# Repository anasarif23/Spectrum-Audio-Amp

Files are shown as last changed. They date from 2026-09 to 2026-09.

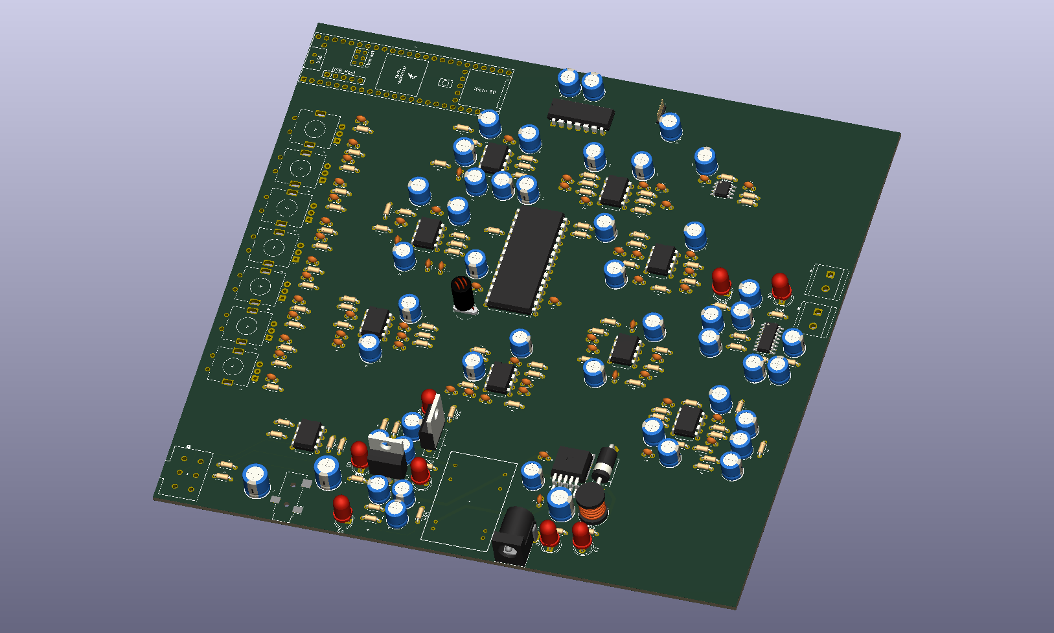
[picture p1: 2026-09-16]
Audio_Amplifier 3D-PIC.png

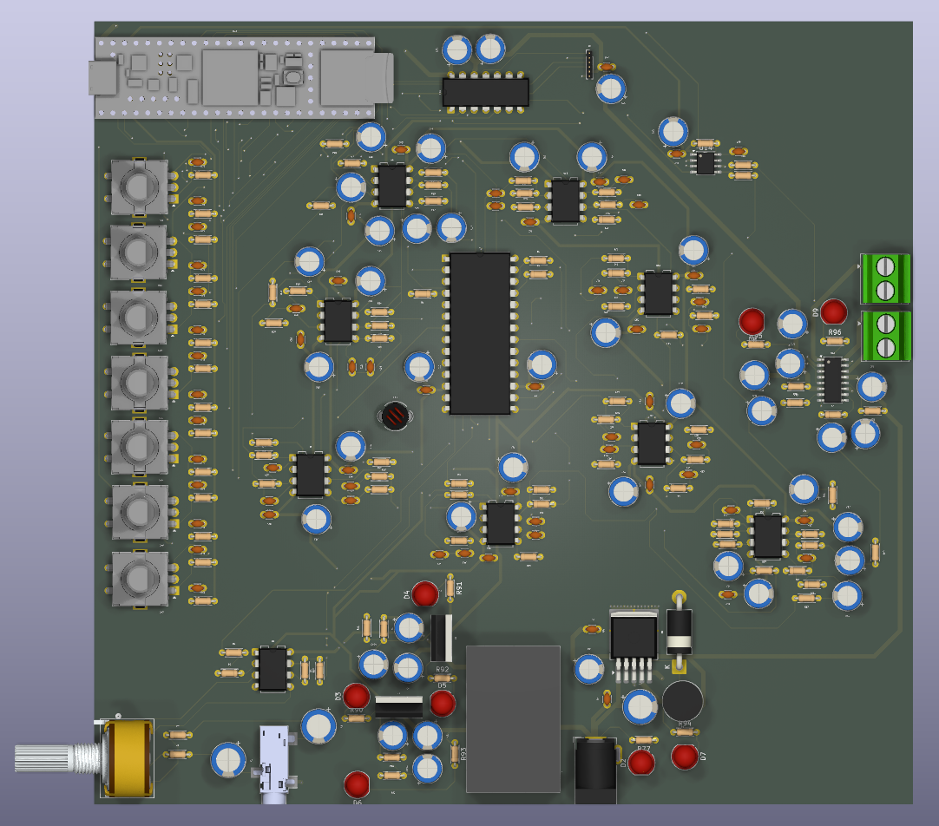
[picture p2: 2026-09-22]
PICS & PDFS/Audio_Amplifier PERFECY SQUARE.png

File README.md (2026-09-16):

## Version 0

The first version of the schematic, completed while learning KiCad fundamentals. This version has some design mistakes that I identified during review, including [add specifics if you can — e.g. incorrect regulator pinout, missing decoupling capacitors, etc.]. I used Claude as a learning resource throughout this stage to understand regulator behavior, KiCad's schematic tools, and best practices for power supply design.

📄 See `Advanced Audio Amplifier Schematic.pdf` for the full Version 0 schematic.

## Version 1

A revised, cleaner version of the schematic with the Version 0 mistakes corrected and the overall layout better organized. This version is still in progress — the schematic is further along, and I'm now working on completing the full PCB layout.

🖼️ See `Audio Amplifier Version 1.png` for the current schematic.

## Version 2

The PCB layout stage — all components have been placed on the board. Routing has not started yet; that's the next step.

📄 See `Audio_Amplifier.pdf` for the schematic and `Audio_Amplifier PCB FULL LAYOUT.pdf` for the current component placement.

🖼️ See `Audio_Amplifier 3D-PIC.png` for a 3D render of the board as placed so far.

---

## Bill of Materials (from schematic)

### Active Components

| Ref | Part | Description |
|-----|---|---|
| U1, U6–U13 | NE5532 | Dual op-amp — used across the pre-amp stage and the 7 gyrator filter bands |
| U2 | LM317-TO220 | Adjustable positive linear regulator |
| U3 | LM337-TO220 | Adjustable negative linear regulator |
| U4 | LM2596S-5 | Switching buck regulator (5V rail) |
| U5 | LMC835N | Graphic equalizer IC |
| U14 | MSGEQ7 | 7-band spectrum analyzer IC |
| U15 | Teensy 4.1 | Microcontroller |
| U16 | SN74AHCT125N | Quad buffer / 3.3V logic level shifter |
| U18 | PAM8403D | Class-D speaker amplifier |
| PS1 | DCWN03A-12 | Isolated DC-DC converter |
| D1 | 1N5822 | Schottky diode |
| D2–D9 | LED | Status/indicator LEDs |
| SW1–SW7 | Rotary Encoder | 7-band control knobs |
| RV1 | 10k | Potentiometer |
| L1 | 33µH | Inductor (buck regulator) |
| FB1 | Ferrite Bead | EMI suppression |
| J1 | SJ-3523-SMT | Audio input jack |
| J2 | Barrel Jack | 12V power input |
| J3, J4 | Screw_Terminal_01x02 | Power/output connections |
| J6 | Conn_01x06 | Pin header |

### Passives

Roughly 96 resistors (R1–R96) and 110 capacitors (C1–C110) make up the gyrator filter networks (tuned for the 63Hz–16kHz bands), op-amp gain/bias networks, and decoupling/filtering throughout the board. Full reference-designator values are in the schematic (`Audio_Amplifier.pdf`).

---

## Status

🚧 **In progress** — schematic complete (Version 1); PCB component placement complete (Version 2), routing still to be done.

## Tools Used

- KiCad (schematic capture, PCB layout)
- NE5532 dual op-amps (pre-amp and gyrator filter stages)
- LM317 / LM337 adjustable linear regulators, LM2596S-5 switching regulator
- MSGEQ7 spectrum analyzer IC, LMC835N graphic equalizer IC
- Teensy 4.1 microcontroller
- PAM8403D class-D amplifier

## What I Learned

Iterating between Version 0 and Version 1 taught me to catch design errors early through review rather than discovering them at the prototyping stage — a habit I now apply to every new project. I also used Claude as a learning tool throughout this project to fill gaps in my coursework, particularly around regulator dropout behavior and KiCad workflow, then applied that understanding directly to my design decisions.

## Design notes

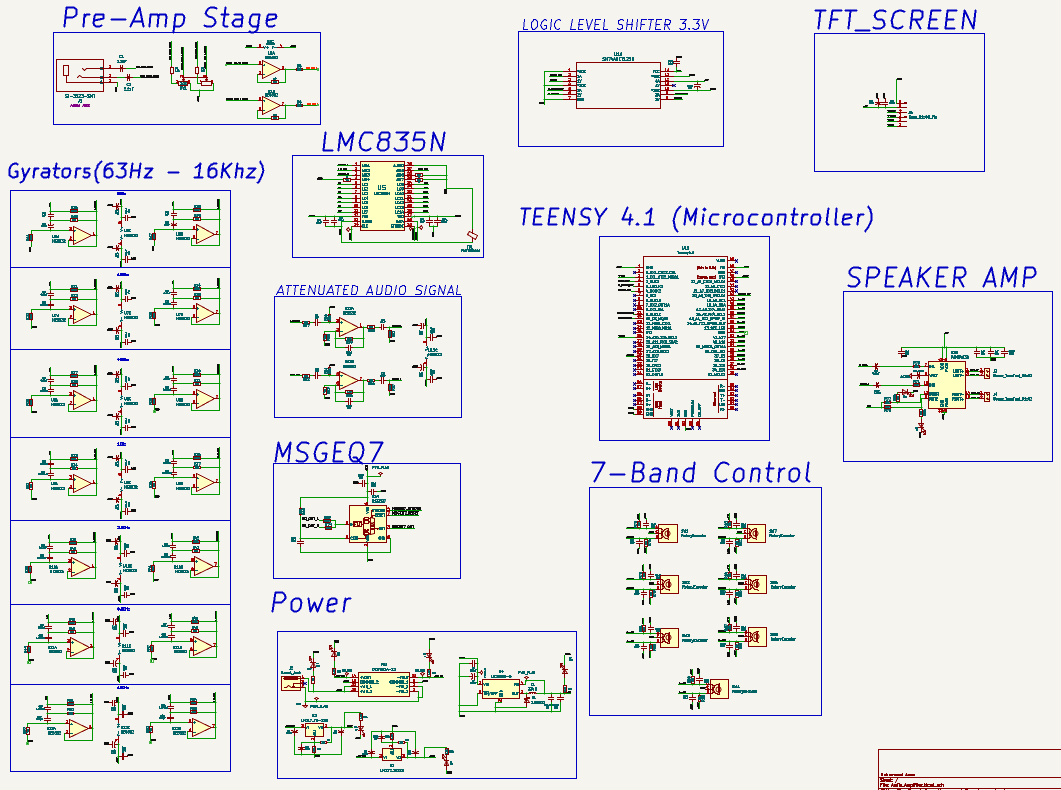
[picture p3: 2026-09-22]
Scehmatic PNG.png

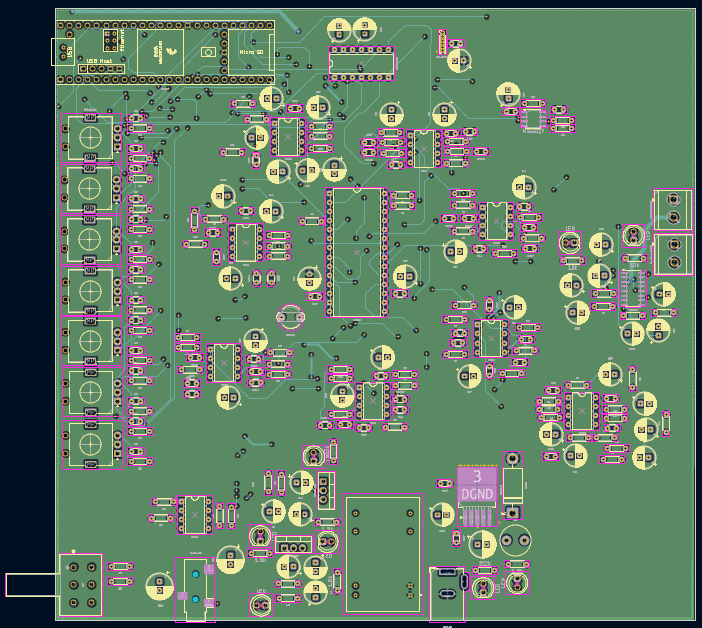
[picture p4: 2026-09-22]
PICS & PDFS/DGND.png

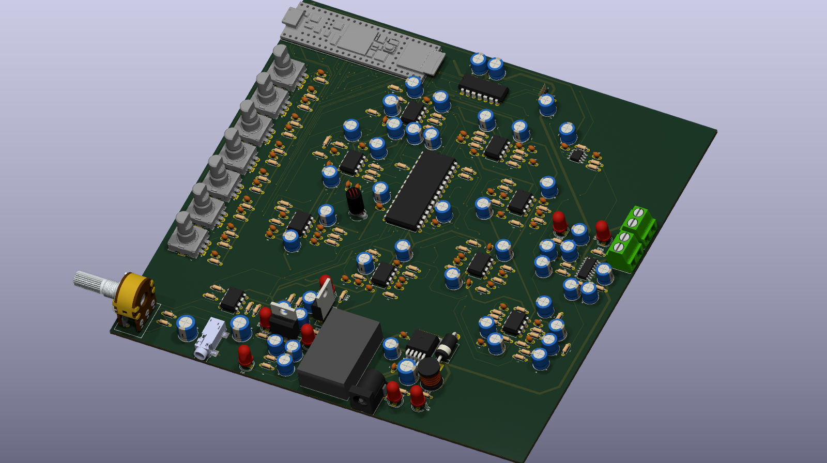
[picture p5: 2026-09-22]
PICS & PDFS/Audio_Amplifier.png

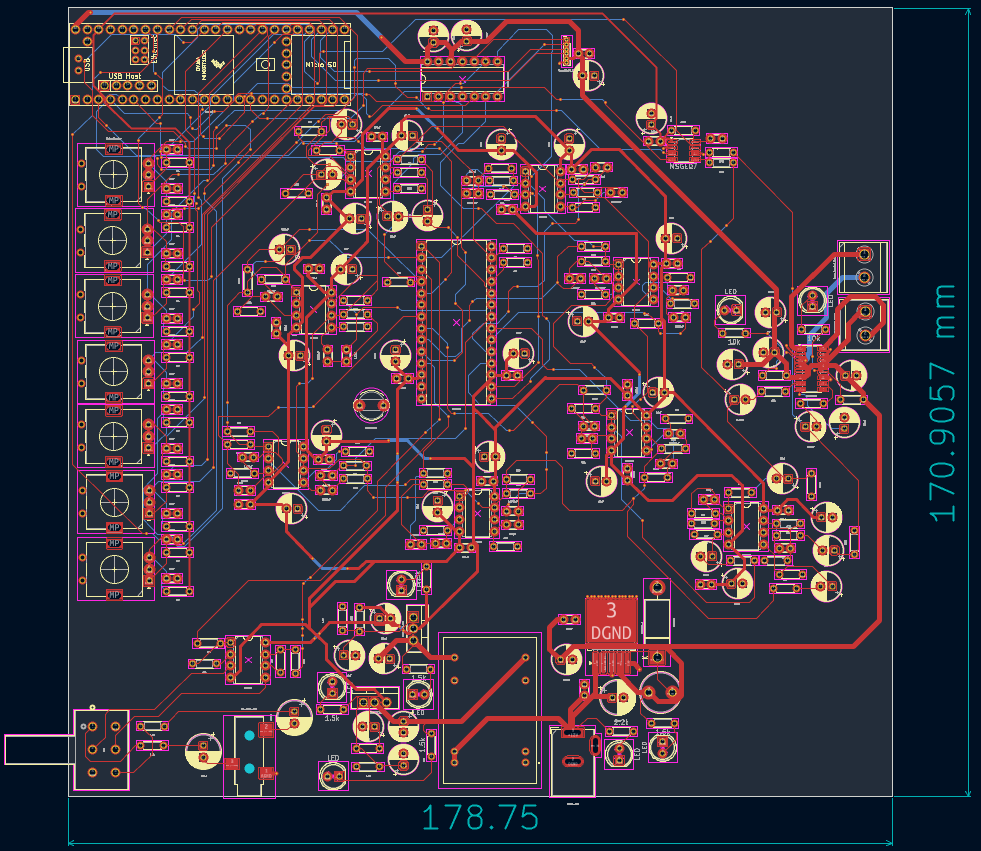
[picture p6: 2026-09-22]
PICS & PDFS/Screenshot 2026-09-20 064418.png

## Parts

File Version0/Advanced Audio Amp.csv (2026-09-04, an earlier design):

Reference | Qty | Value | DNP | Exclude from BOM | Exclude from Board | Footprint | Datasheet
A1 | 1 | Arduino_Nano_v3.x |  |  |  | Module:Arduino_Nano | http://www.mouser.com/pdfdocs/Gravitech_Arduino_Nano3_0.pdf
C1,C2,C4,C8 | 4 | 1uF
C3,C5,C9,C11,C41,C42,C61,C63,C65,C67,C76,C79 | 12 | 10uF
C6,C58,C59 | 3 | 33pF
C7,C10,C14,C43,C44,C45,C46,C47,C48,C49,C50,C51,C52,C53,C54,C55,C56,C57,C60,C62,C64,C66,C68,C74,C75,C80 | 26 | 100nF
C12,C13 | 2 | 2.2uF
C15,C16 | 2 | 0.1uF
C17,C19 | 2 | 0.033uF
C18,C20 | 2 | 0.47uF
C21,C23 | 2 | 0.015uF
C22,C24 | 2 | 0.15uF
C25,C27 | 2 | 0.0068uF
C26,C28 | 2 | 0.068uF
C29,C31 | 2 | 0.0033uF
C30,C32 | 2 | 0.022uF
C33,C35 | 2 | 0.0015uF
C34,C36 | 2 | 0.01uF
C37,C39 | 2 | 680pF
C38,C40 | 2 | 0.0047uF
C69 | 1 | 100pF
C70,C71 | 2 | C_Small_US
C72 | 1 | C_Small
J1 | 1 | AudioPlug3
LS3,LS4 | 2 | 4Ω 3W
R1,R2,R17,RV1,RV3,RV4,RV5,RV6,RV7,RV8 | 10 | 10k
R3,R12,R19,R22,R23,R25,R26,R28,R29,R31,R32,R34,R35,R38,R41,R44,R47,R50,R53,R56,R63,R64,R65,R66 | 24 | 100k
R4,R5 | 2 | 22k
R6,R10,R18,R59 | 4 | 100
R7,R14 | 2 | 470
R8,R9,R11,R13 | 4 | 6.8k
R15 | 1 | 200k
R16,RV2 | 2 | 10K
R20,R21,R24,R27,R30,R33,R36,R39,R42,R45,R48,R51,R54,R57 | 14 | 680
R37,R40,R43,R46 | 4 | 82K
R49,R52 | 2 | 62k
R55,R58 | 2 | 47k
R60,R61,R62 | 3 | 47K
R67,R68,R69,R70,R71,R72,R73 | 7 | 47
R74,R75,R76,R78 | 4 | 1k
R77 | 1 | R_Small_US
U1,U2,U3,U4,U5,U6,U8,U11,U12 | 9 | NE5532 |  |  |  |  | http://www.ti.com/lit/ds/symlink/ne5532.pdf
U7,U14 | 2
U9 | 1 | PAM8403D |  |  |  | Package_SO:SOIC-16_3.9x9.9mm_P1.27mm | https://www.diodes.com/assets/Datasheets/products_inactive_data/PAM8403.pdf
U10 | 1 | MSGEQ7 |  |  |  |  | http://mix-sig.com/images/datasheets/MSGEQ7.pdf
U13 | 1 | CD4051B |  |  |  |  | http://www.ti.com/lit/ds/symlink/cd4052b.pdf

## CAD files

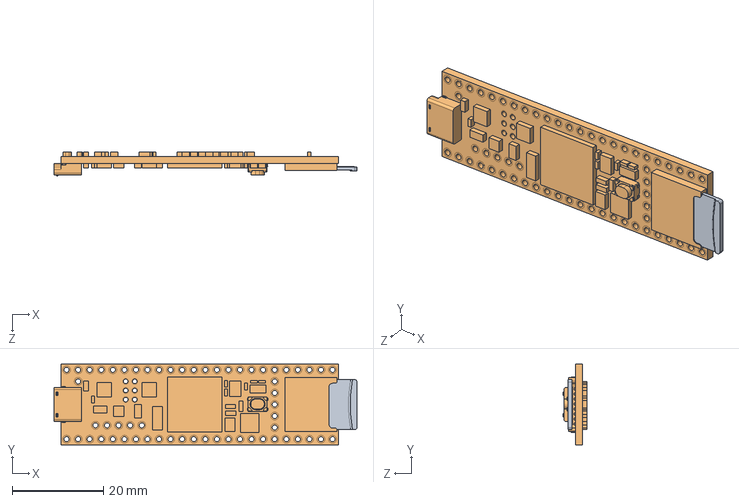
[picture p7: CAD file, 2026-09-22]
CIRCUIT BOARD,TEENSY 4.10.STEP
66.6 x 17.8 x 5.27 mm

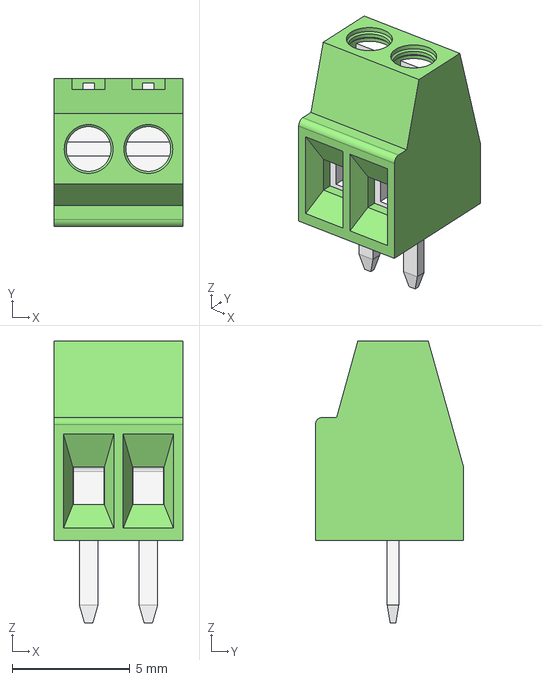
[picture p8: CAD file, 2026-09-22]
KF128-2.54-2P.step
5.48 x 6.30 x 12.0 mm
Connector_body

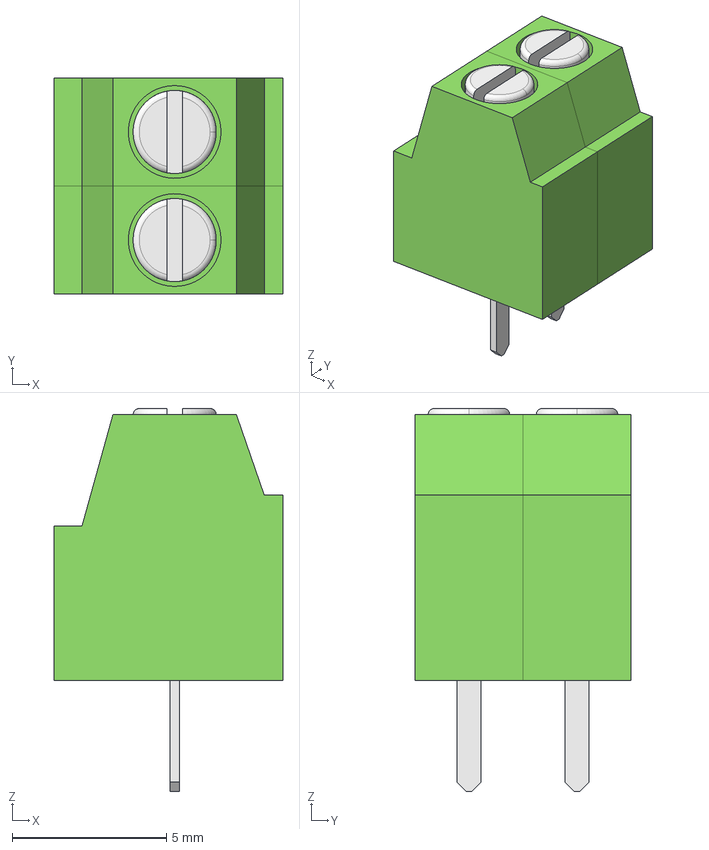
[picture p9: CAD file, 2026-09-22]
KF128-3.5-2P.step
7.40 x 7.00 x 12.4 mm

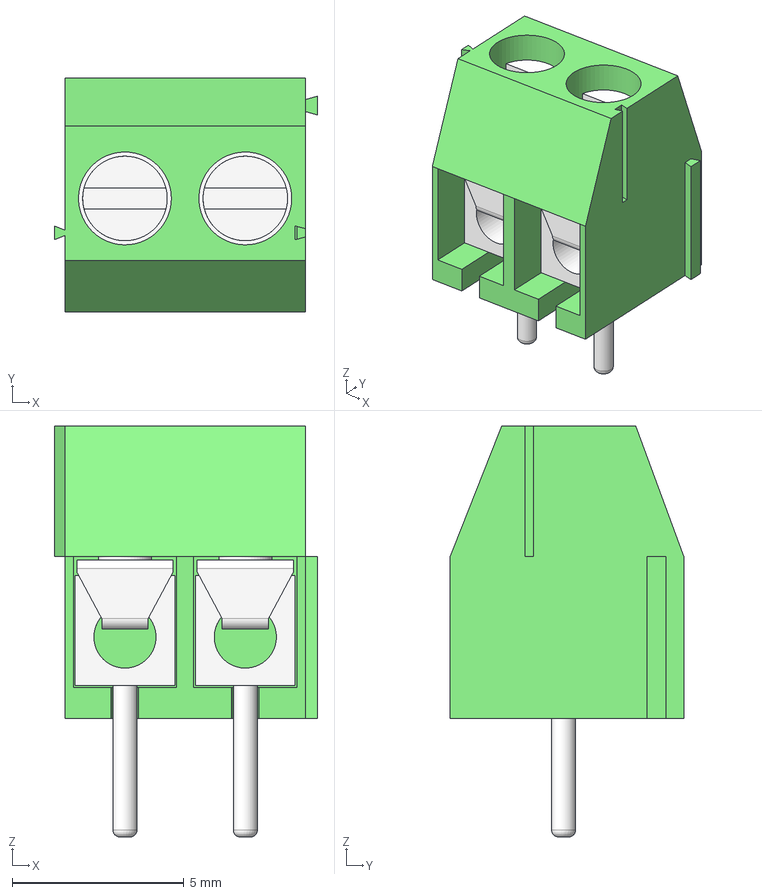
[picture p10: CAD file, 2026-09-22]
KF350-2p.step
7.65 x 6.80 x 11.9 mm
Corps
Conn_1
Conn_2
blade_1
blade_2
Vis_1
Vis_001

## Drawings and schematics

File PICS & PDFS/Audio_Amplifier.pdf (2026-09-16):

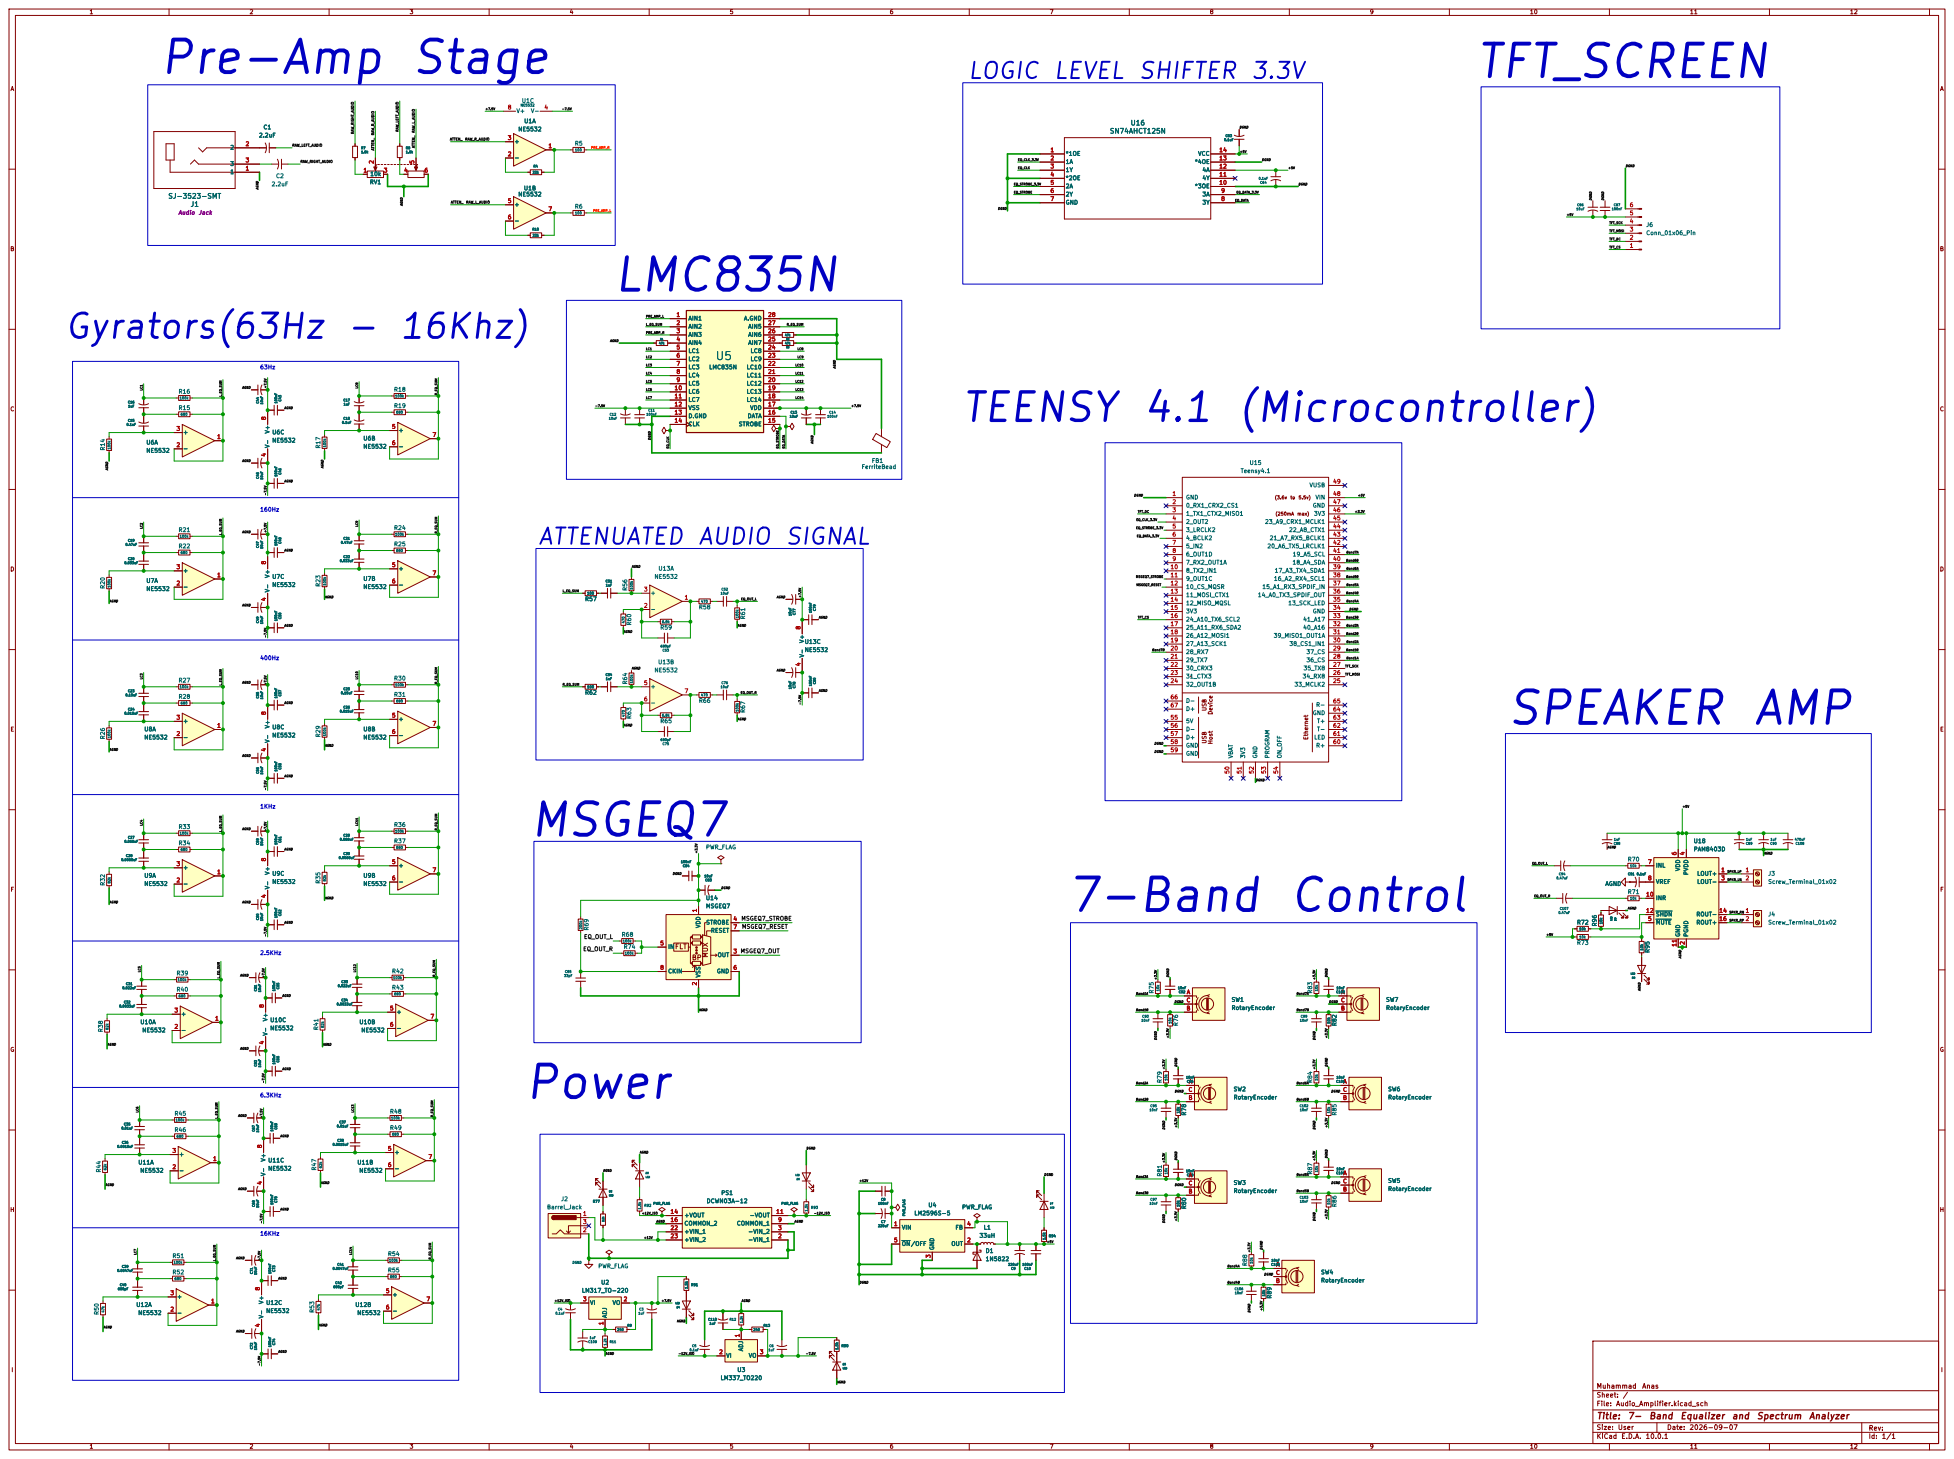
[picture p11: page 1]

100nF USB USB Device Host

Muhammad Anas
Sheet: /
File: Audio_Amplifier.kicad_sch
Title: 7- Band Equalizer and Spectrum Analyzer

Size: User | Rev:
KiCad E.D.A. 10.0.1 | Id: 1/1

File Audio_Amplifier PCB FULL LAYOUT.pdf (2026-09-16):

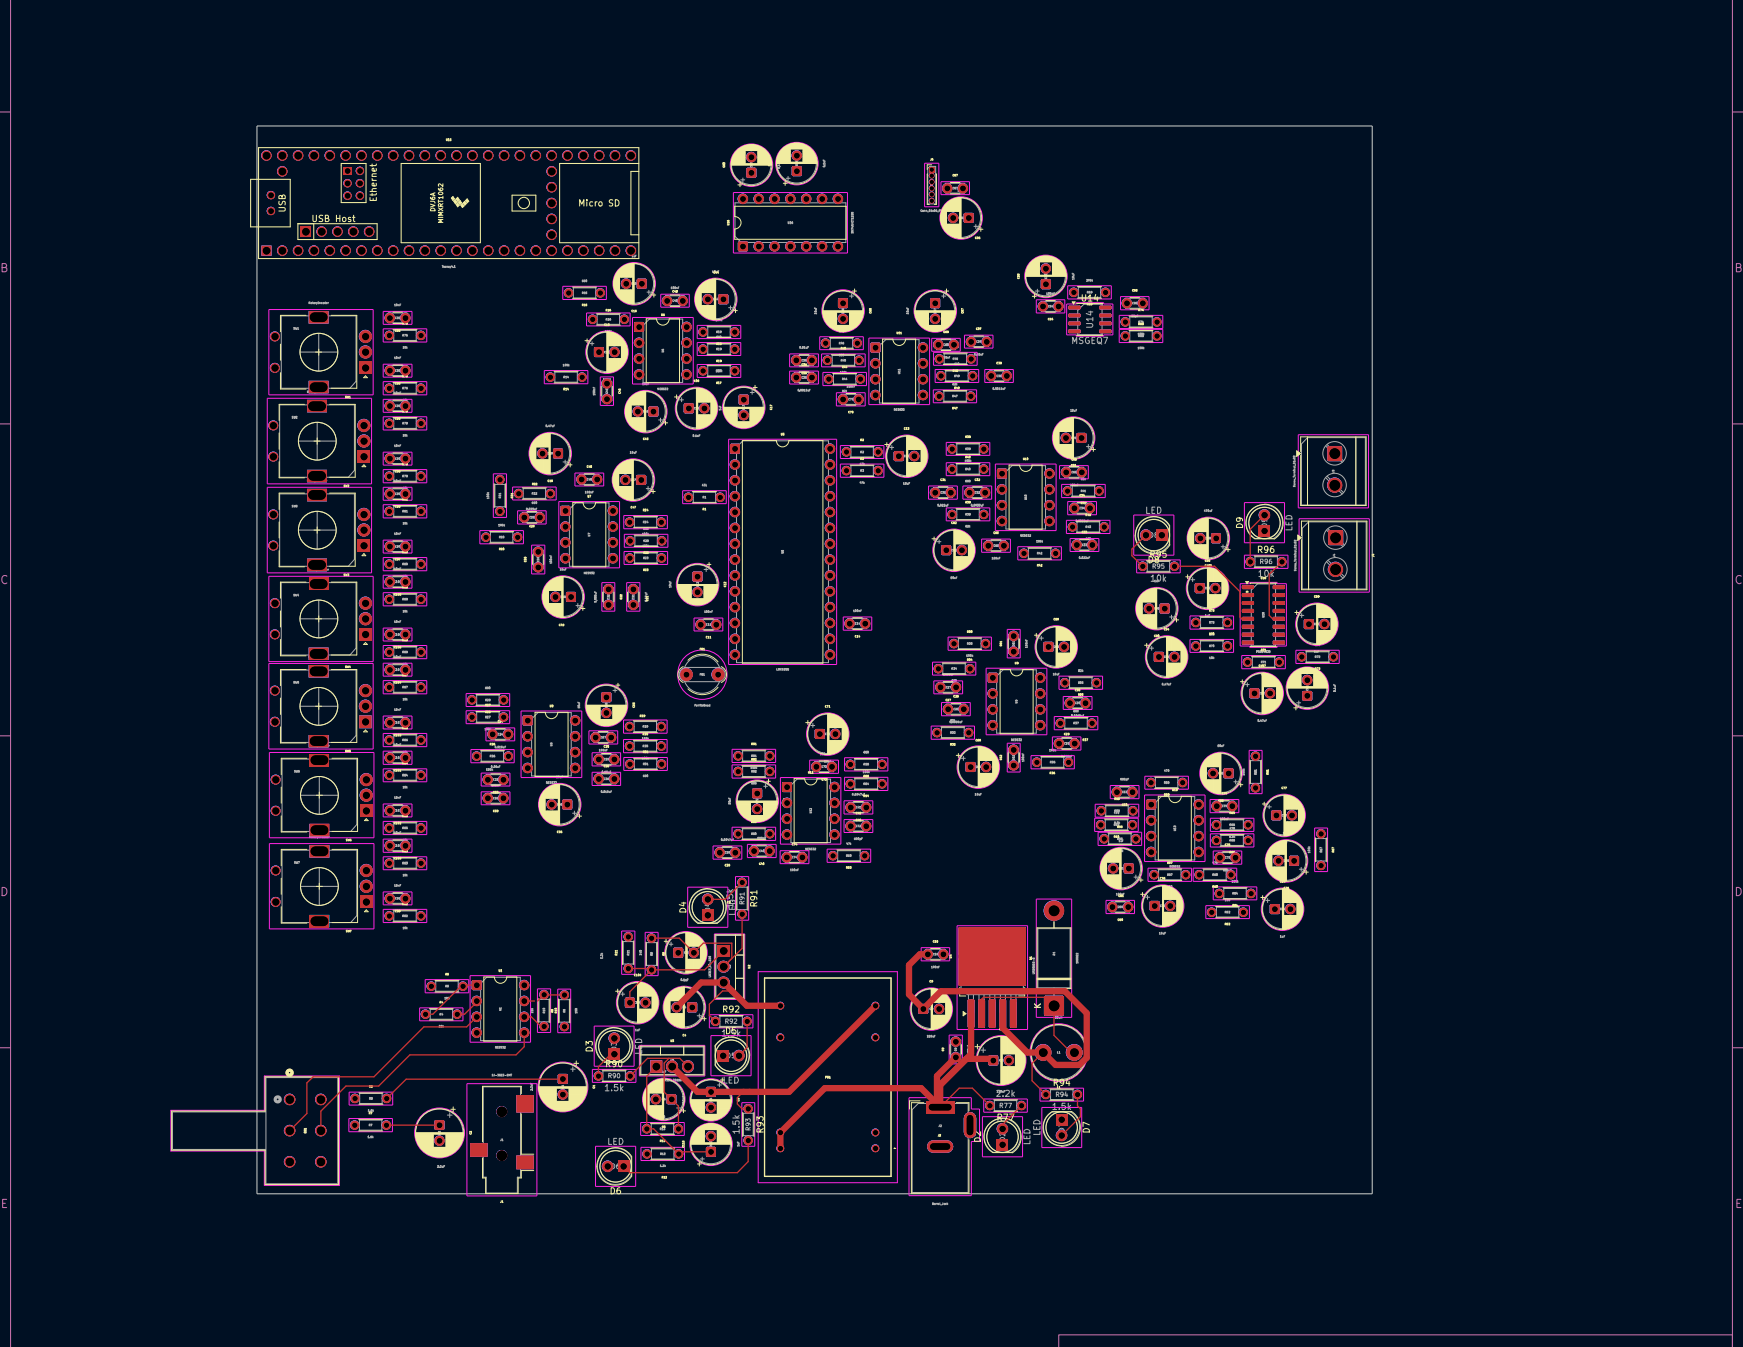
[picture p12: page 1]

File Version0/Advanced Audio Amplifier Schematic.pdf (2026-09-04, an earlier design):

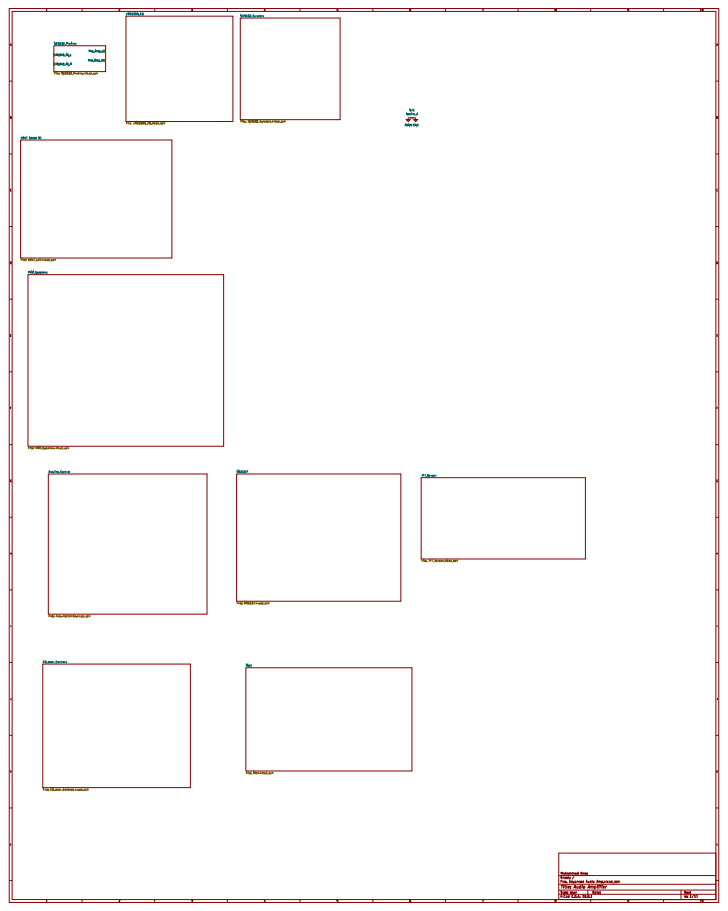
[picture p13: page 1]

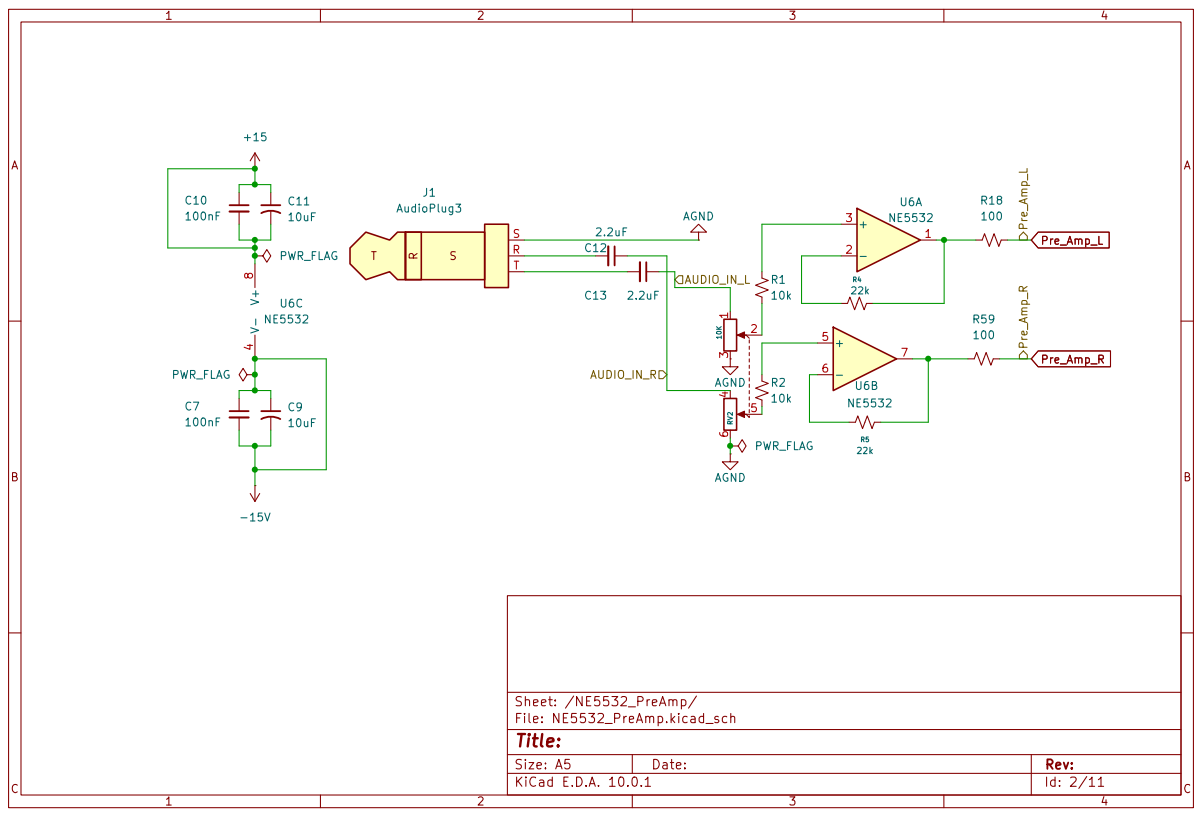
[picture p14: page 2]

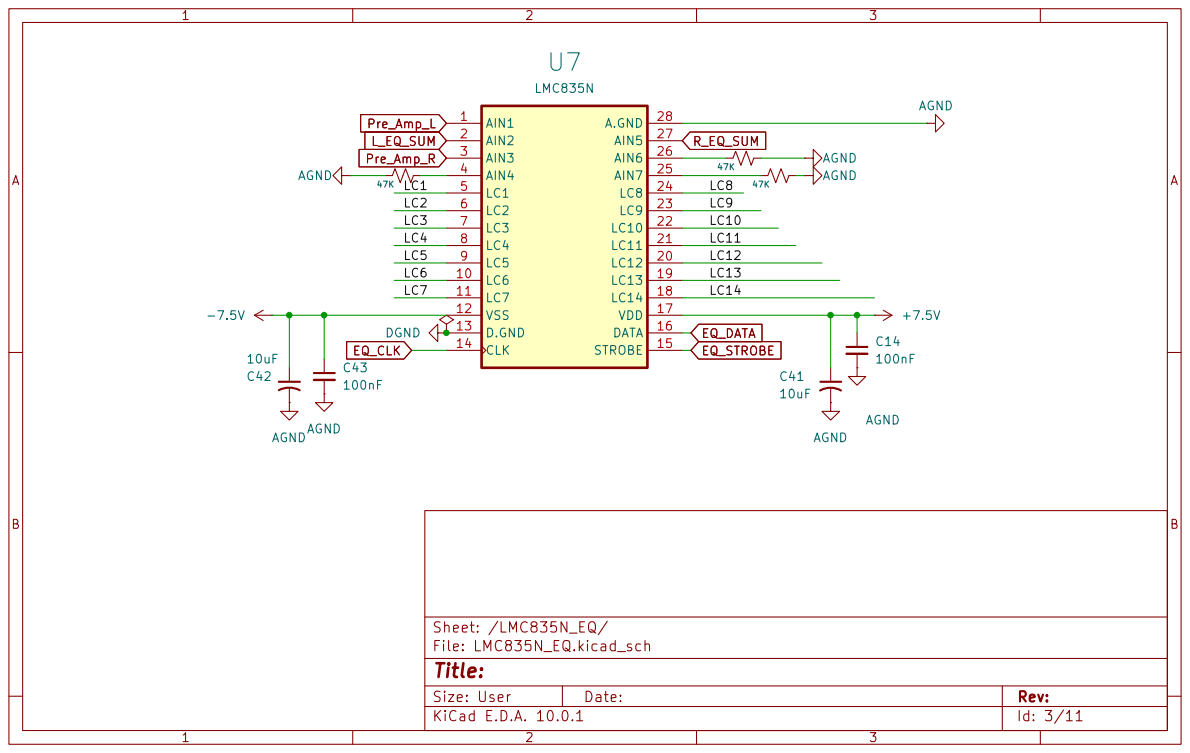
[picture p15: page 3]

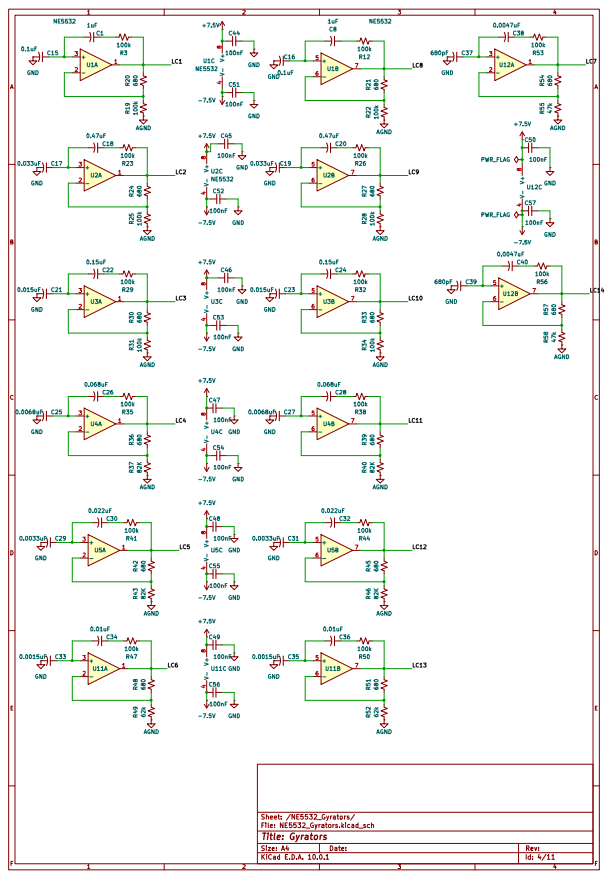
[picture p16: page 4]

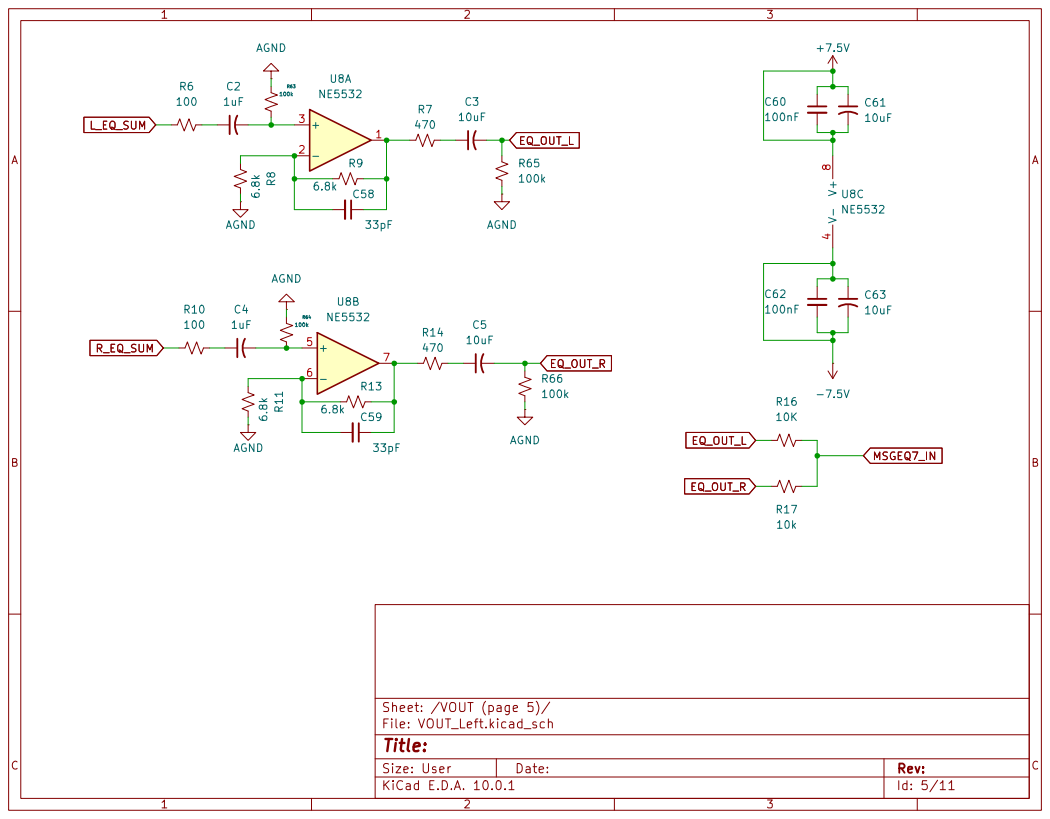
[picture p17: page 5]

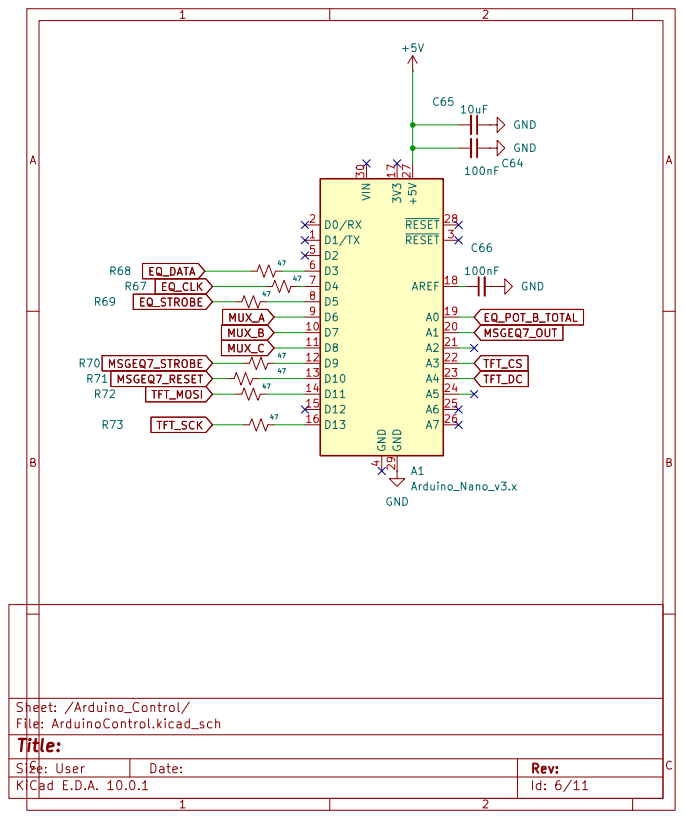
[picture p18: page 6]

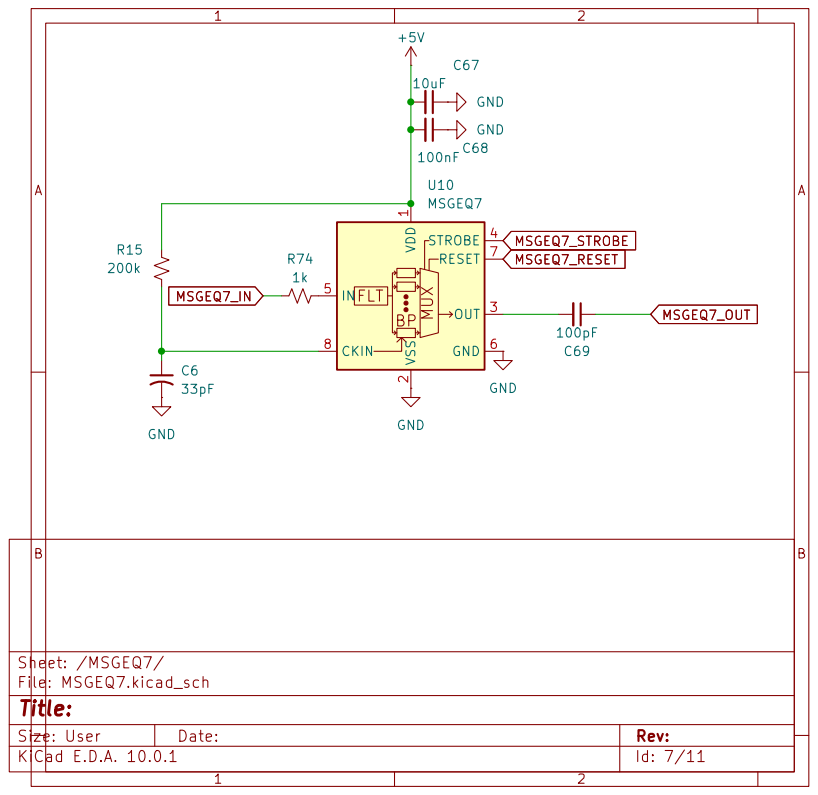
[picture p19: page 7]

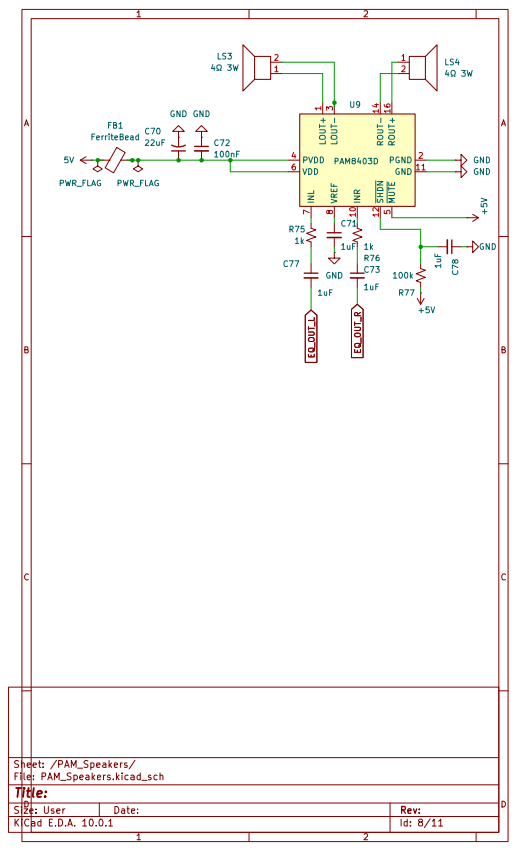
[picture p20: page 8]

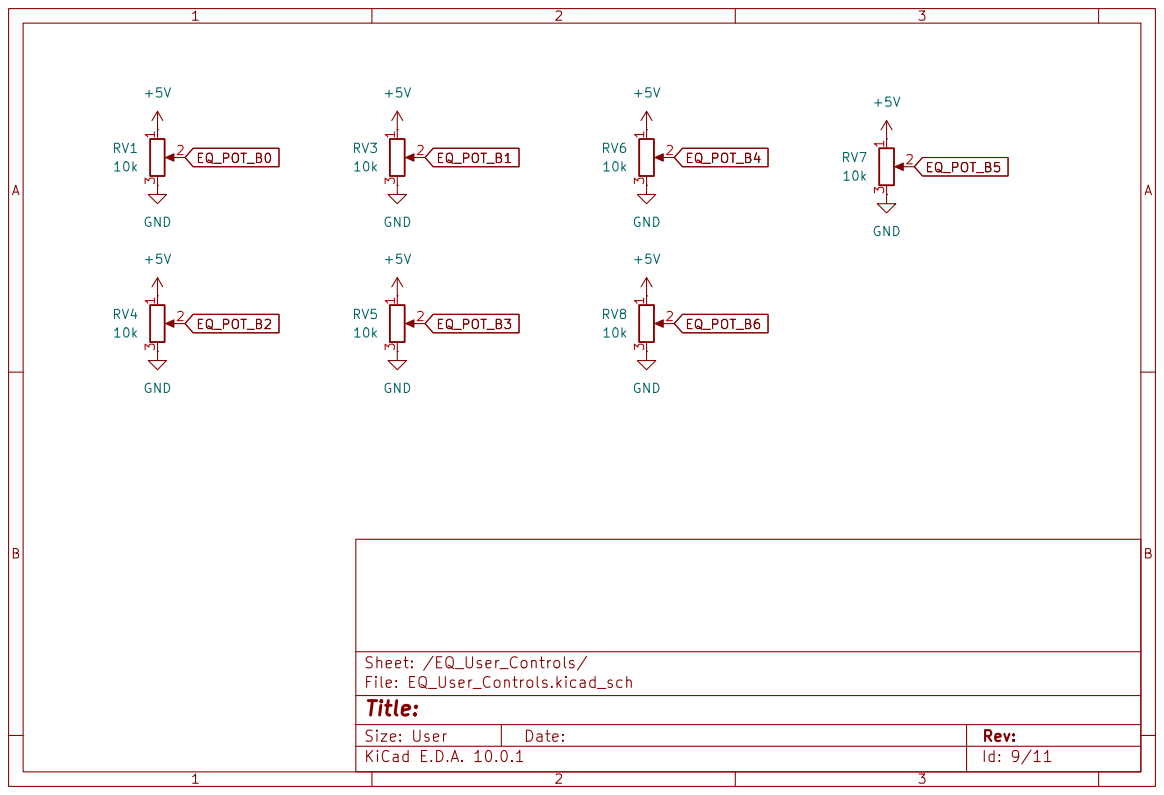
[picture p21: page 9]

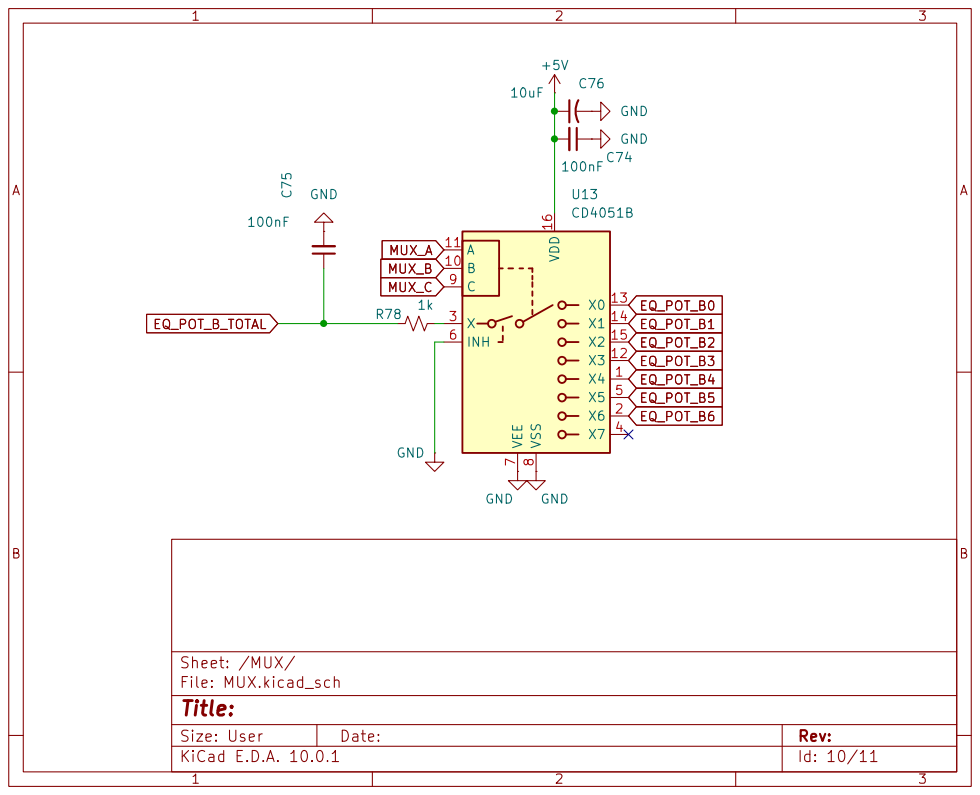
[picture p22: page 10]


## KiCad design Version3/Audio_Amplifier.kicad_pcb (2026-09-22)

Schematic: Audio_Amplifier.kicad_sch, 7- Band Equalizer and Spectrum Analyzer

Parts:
C1, C2: 2.2uF; CP_Radial_D7.5mm_P2.50mm
C3, C6, C16, C17, C51, C54, C88, C89, C90, C109, C110: 1uF; CP_Radial_D6.3mm_P2.50mm
C4, C5, C15, C18, C63, C64, C91: 0.1uF; CP_Radial_D6.3mm_P2.50mm
C7: 220uF; CP_Radial_D7.5mm_P2.50mm
C8, C10, C11, C14, C43, C46, C48, C50, C57, C58, C61, C62, C65, C66, C69, C70, C73, C74, C79, C80, C84, C87: 100nF; C_Disc_D3.0mm_W1.6mm_P2.50mm
C9: 220uF; CP_Radial_D6.3mm_P2.50mm
C12, C13, C44, C45, C47, C49, C52, C55, C56, C59, C60, C67, C68, C71, C72, C76, C77, C78, C81, C82, C83, C86: 10uF; CP_Radial_D6.3mm_P2.50mm
C19, C94, C107: 0.47uF; CP_Radial_D6.3mm_P2.50mm
C20, C22: 0.033uF; C_Disc_D3.0mm_W1.6mm_P2.50mm
C21: 0.47uF; C_Disc_D3.0mm_W1.6mm_P2.50mm
C23, C25: 0.15uF; C_Disc_D3.0mm_W1.6mm_P2.50mm
C24, C26: 0.015uF; C_Disc_D3.0mm_W1.6mm_P2.50mm
C27, C29: 0.068uF; C_Disc_D3.0mm_W1.6mm_P2.50mm
C28, C30: 0.0068uF; C_Disc_D3.0mm_W1.6mm_P2.50mm
C31, C33: 0.022uF; C_Disc_D3.0mm_W1.6mm_P2.50mm
C32, C34: 0.0033uF; C_Disc_D3.0mm_W1.6mm_P2.50mm
C35, C37: 0.01uF; C_Disc_D3.0mm_W1.6mm_P2.50mm
C36, C38: 0.0015uF; C_Disc_D3.0mm_W1.6mm_P2.50mm
C39, C41: 0.0047uF; C_Disc_D3.0mm_W1.6mm_P2.50mm
C40, C42, C53, C75: 680pF; C_Disc_D3.0mm_W1.6mm_P2.50mm
C85: 33pF; C_Disc_D3.0mm_W1.6mm_P2.50mm
C92, C93, C95, C96, C97, C98, C99, C100, C101, C102, C103, C104, C105, C106: 10nF; C_Disc_D3.0mm_W1.6mm_P2.50mm
C108: 470uF; CP_Radial_D6.3mm_P2.50mm
D1: 1N5822; D_DO-201AD_P15.24mm_Horizontal
D2, D3, D4, D5, D6, D7, D8, D9: LED; LED_D5.0mm
FB1: FerriteBead; LairdTech_28C0236-0JW-10
J1: SJ-3523-SMT; Jack_3.5mm_CUI_SJ-3523-SMT_Horizontal
J2: Barrel_Jack; BarrelJack_GCT_DCJ200-10-A_Horizontal
J3, J4: Screw_Terminal_01x02; TerminalBlock_CUI_TB007-508-02_1x02_P5.08mm_Horizontal
J6: Conn_01x06_Pin; PinHeader_1x06_P1.00mm_Vertical
L1: 33uH; L_Radial_D8.7mm_P5.00mm_Fastron_07HCP
PS1: DCWN03A-12; DCWN03A12; Mouser Part Number 709-DCWN03A-12
R1, R2, R3, R50, R53: 47k; R_Axial_DIN0204_L3.6mm_D1.6mm_P5.08mm_Horizontal
R4, R10: 22k; R_Axial_DIN0204_L3.6mm_D1.6mm_P5.08mm_Horizontal
R5, R6, R57, R62: 100; R_Axial_DIN0204_L3.6mm_D1.6mm_P5.08mm_Horizontal
R7, R8: 1.8k; R_Axial_DIN0204_L3.6mm_D1.6mm_P5.08mm_Horizontal
R9, R13: 240; R_Axial_DIN0204_L3.6mm_D1.6mm_P5.08mm_Horizontal
R11, R12: 1.2k; R_Axial_DIN0204_L3.6mm_D1.6mm_P5.08mm_Horizontal
R14, R16, R17, R18, R20, R21, R23, R24, R26, R27, R29, R30, R33, R36, R39, R42, R45, R48, R51, R54, R56, R61, R64, R67, R68, R74: 100k; R_Axial_DIN0204_L3.6mm_D1.6mm_P5.08mm_Horizontal
R15, R19, R22, R25, R28, R31, R34, R37, R40, R43, R46, R49, R52, R55: 680; R_Axial_DIN0204_L3.6mm_D1.6mm_P5.08mm_Horizontal
R32, R35, R38, R41: 82k; R_Axial_DIN0204_L3.6mm_D1.6mm_P5.08mm_Horizontal
R44, R47: 62k; R_Axial_DIN0204_L3.6mm_D1.6mm_P5.08mm_Horizontal
R58, R60, R63, R66: 470; R_Axial_DIN0204_L3.6mm_D1.6mm_P5.08mm_Horizontal
R59, R65: 6.8k; R_Axial_DIN0204_L3.6mm_D1.6mm_P5.08mm_Horizontal
R69: 200k; R_Axial_DIN0204_L3.6mm_D1.6mm_P5.08mm_Horizontal
R70, R71, R72, R73, R75, R76, R78, R79, R80, R81, R82, R83, R84, R85, R86, R87, R88, R89, R95, R96: 10k; R_Axial_DIN0204_L3.6mm_D1.6mm_P5.08mm_Horizontal
R77: 2.2k; R_Axial_DIN0204_L3.6mm_D1.6mm_P5.08mm_Horizontal
R90, R91, R92, R93, R94: 1.5k; R_Axial_DIN0204_L3.6mm_D1.6mm_P5.08mm_Horizontal
RV1: 10k; POT_PDB182_BRN
SW1, SW2, SW3, SW4, SW5, SW6, SW7: RotaryEncoder; RotaryEncoder_Alps_EC11E_Vertical_H20mm
U1, U6, U7, U8, U9, U10, U11, U12, U13: NE5532; DIP-8_W7.62mm
U2: LM317_TO-220; TO-220-3_Vertical
U3: LM337_TO220; TO-220-3_Vertical
U4: LM2596S-5; TO-263-5_TabPin3
U5: LMC835N; DIP-28_W15.24mm
U14: MSGEQ7; SOIC-8_3.9x4.9mm_P1.27mm
U15: Teensy4.1; Teensy41
U16: SN74AHCT125N; DIP-14_W7.62mm
U18: PAM8403D; SOIC-16_3.9x9.9mm_P1.27mm

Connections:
/+3.3V: C83.1, C84.1, R69.2, R75.2, R76.2, R78.2, R79.2, R80.2, R81.2, R82.2, R83.2, R84.2, R85.2, R86.2, R87.2, R88.2, R89.2, U14.1 (VDD), U15.46 (3V3)
/+5V: C9.1, C10.1, C63.1, C64.1, C86.2, C87.1, C88.1, C89.1, C90.1, C108.1, J6.5, L1.2, R72.1, R73.1, R94.1, U4.4 (FB), U15.48 (VIN), U16.12 (4A), U16.14 (VCC), U18.4 (PVDD), U18.6 (VDD), U18.13 (PVDD)
/+7.5V: C3.2, C13.2, C14.2, C43.1, C44.2, C47.2, C48.1, C55.2, C57.1, C59.2, C61.1, C65.1, C67.2, C69.1, C71.2, C73.1, C77.1, C79.1, C81.2, R9.1, R91.2, U1.8 (V+), U2.2 (VO), U5.17 (VDD), U6.8 (V+), U7.8 (V+), U8.8 (V+), U9.8 (V+), U10.8 (V+), U11.8 (V+), U12.8 (V+), U13.8 (V+)
/+12V: C7.1, C8.1, J2.1, PS1.22 (+VIN_1), PS1.23 (+VIN_2), R77.2, U4.1 (VIN)
/+12V_ISO: C4.2, PS1.14 (+VOUT), R92.1, U2.3 (VI)
/-7.5V: C6.1, C11.2, C12.2, C45.2, C46.1, C49.2, C50.1, C56.2, C58.1, C60.2, C62.1, C66.1, C68.2, C70.1, C72.2, C74.1, C78.1, C80.1, C82.2, R13.1, R90.2, U1.4 (V-), U3.3 (VO), U5.12 (VSS), U6.4 (V-), U7.4 (V-), U8.4 (V-), U9.4 (V-), U10.4 (V-), U11.4 (V-), U12.4 (V-), U13.4 (V-)
/-12V_ISO: C5.1, PS1.11 (-VOUT), R93.1, U3.2 (VI)
/ATTEN_ RAW_L_AUDIO: RV1.5, U1.5 (+)
/ATTEN_ RAW_R_AUDIO: RV1.2, U1.3 (+)
/Band1A: C92.2, R75.1, SW1.A, U15.28 (36_CS)
/Band1B: C93.2, R76.1, SW1.B, U15.29 (37_CS)
/Band2A: C96.2, R79.1, SW2.A, U15.30 (38_CS1_IN1)
/Band2B: C95.2, R78.1, SW2.B, U15.31 (39_MISO1_OUT1A)
/Band3A: C98.2, R81.1, SW3.A, U15.32 (40_A16)
/Band3B: C97.2, R80.1, SW3.B, U15.33 (41_A17)
/Band4A: C105.2, R88.1, SW4.A, U15.35 (13_SCK_LED)
/Band4B: C106.2, R89.1, SW4.B, U15.36 (14_A0_TX3_SPDIF_OUT)
/Band5A: C104.2, R87.1, SW5.A, U15.37 (15_A1_RX3_SPDIF_IN)
/Band5B: C103.2, R86.1, SW5.B, U15.38 (16_A2_RX4_SCL1)
/Band6A: C101.2, R84.1, SW6.A, U15.39 (17_A3_TX4_SDA1)
/Band6B: C102.2, R85.1, SW6.B, U15.40 (18_A4_SDA)
/Band7A: C100.2, R83.1, SW7.A, U15.41 (19_A5_SCL)
/Band7B: C99.2, R82.1, SW7.B, U15.20 (28_RX7)
/EQ_CLK: U5.14 (CLK), U16.3 (1Y)
/EQ_CLK_3.3V: U15.4 (2_OUT2), U16.2 (1A)
/EQ_DATA: U5.16 (DATA), U16.8 (3Y)
/EQ_DATA_3.3V: U15.6 (4_BCLK2), U16.9 (3A)
/EQ_OUT_L: C52.1, C94.1, R61.2, R68.2
/EQ_OUT_R: C76.1, C107.1, R67.2, R74.2
/EQ_STROBE: U5.15 (STROBE), U16.6 (2Y)
/EQ_STROBE_3.3V: U15.5 (3_LRCLK2), U16.5 (2A)
/LC1: C16.2, R16.1, U5.5 (LC1)
/LC2: C19.2, R21.1, U5.6 (LC2)
/LC3: C23.2, R27.1, U5.7 (LC3)
/LC4: C27.2, R33.1, U5.8 (LC4)
/LC5: C31.2, R39.1, U5.9 (LC5)
/LC6: C35.2, R45.1, U5.10 (LC6)
/LC7: C39.2, R51.1, U5.11 (LC7)
/LC8: C17.2, R18.1, U5.24 (LC8)
/LC9: C21.2, R24.1, U5.23 (LC9)
/LC10: C25.2, R30.1, U5.22 (LC10)
/LC11: C29.2, R36.1, U5.21 (LC11)
/LC12: C33.2, R42.1, U5.20 (LC12)
/LC13: C37.2, R48.1, U5.19 (LC13)
/LC14: C41.2, R54.1, U5.18 (LC14)
/L_EQ_SUM: R15.2, R16.2, R21.2, R22.2, R27.2, R28.2, R33.2, R34.2, R39.2, R40.2, R45.2, R46.2, R51.2, R52.2, R57.2, U5.2 (AIN2), U6.1, U6.2 (-), U7.1, U7.2 (-), U8.1, U8.2 (-), U9.1, U9.2 (-), U10.1, U10.2 (-), U11.1, U11.2 (-), U12.1, U12.2 (-)
/MSGEQ7_OUT: U14.3 (OUT), U15.42 (20_A6_TX5_LRCLK1)
/MSGEQ7_RESET: U14.7 (RESET), U15.12 (10_CS_MQSR)
/MSGEQ7_STROBE: U14.4 (STROBE), U15.11 (9_OUT1C)
/PRE_AMP_L: R6.1, U5.1 (AIN1)
/PRE_AMP_R: R5.1, U5.3 (AIN3)
/RAW_LEFT_AUDIO: C1.1, R8.2
/RAW_RIGHT_AUDIO: C2.1, R7.2
/R_EQ_SUM: R18.2, R19.2, R24.2, R25.2, R30.2, R31.2, R36.2, R37.2, R42.2, R43.2, R48.2, R49.2, R54.2, R55.2, R62.2, U5.27 (AIN5), U6.6 (-), U6.7, U7.6 (-), U7.7, U8.6 (-), U8.7, U9.6 (-), U9.7, U10.6 (-), U10.7, U11.6 (-), U11.7, U12.6 (-), U12.7
/SPKR_LN: J3.2, U18.3 (LOUT-)
/SPKR_LP: J3.1, U18.1 (LOUT+)
/SPKR_RN: J4.1, U18.14 (ROUT-)
/SPKR_RP: J4.2, U18.16 (ROUT+)
/TFT_CS: J6.1, U15.16 (24_A10_TX6_SCL2)
/TFT_DC: J6.2, U15.3 (1_TX1_CTX2_MISO1)
/TFT_MOSI: J6.3, U15.26 (34_RX8)
/TFT_SCK: J6.4, U15.27 (35_TX8)
AGND: C3.1, C4.1, C5.2, C6.2, C13.1, C14.1, C43.2, C44.1, C45.1, C46.2, C47.1, C48.2, C49.1, C50.2, C55.1, C56.1, C57.2, C58.2, C59.1, C60.1, C61.2, C62.2, C65.2, C66.2, C67.1, C68.1, C69.2, C70.2, C71.1, C72.1, C73.2, C74.2, C77.2, C78.2, C79.2, C80.2, C81.1, C82.1, C85.2, C88.2, C89.2, C90.2, C91.2, C108.2, C109.2, C110.2, D3.2 (A), D4.1 (K), D5.1 (K), D6.2 (A), D8.1 (K), D9.1 (K), FB1.1, J1.1, PS1.9 (COMMON_1), PS1.16 (COMMON_2), R1.2, R2.2, R3.2, R11.2, R12.1, R14.1, R17.1, R20.1, R23.1, R26.1, R29.1, R32.1, R35.1, R38.1, R41.1, R44.1, R47.1, R50.1, R53.1, R56.1, R60.2, R61.1, R63.2, R64.1, R67.1, RV1.3, RV1.6, U5.28 (A.GND), U14.2 (VSS), U14.6 (GND), U18.2 (PGND), U18.11 (GND), U18.15 (PGND)
DGND: C7.2, C8.2, C9.2, C10.2, C11.1, C12.1, C63.2, C64.2, C83.2, C84.2, C86.1, C87.2, C92.1, C93.1, C95.1, C96.1, C97.1, C98.1, C99.1, C100.1, C101.1, C102.1, C103.1, C104.1, C105.1, C106.1, D1.2 (A), D2.1 (K), D7.1 (K), FB1.2, J2.2, J6.6, PS1.2 (-VIN_1), PS1.3 (-VIN_2), SW1.C, SW2.C, SW3.C, SW4.C, SW5.C, SW6.C, SW7.C, U4.3 (GND), U4.5 (~ON/OFF), U5.13 (D.GND), U15.1 (GND), U15.34 (GND), U15.52 (GND), U15.58 (GND), U15.59 (GND), U16.1 (*1OE), U16.4 (*2OE), U16.7 (GND), U16.10 (*3OE), U16.13 (*4OE)
unnamed: C1.2, J1.2
unnamed: C2.2, J1.3
unnamed: C15.2, C16.1, R15.1
unnamed: C17.1, C18.2, R19.1
unnamed: C19.1, C20.2, R22.1
unnamed: C21.1, C22.2, R25.1
unnamed: C23.1, C24.2, R28.1
unnamed: C25.1, C26.2, R31.1
unnamed: C27.1, C28.2, R34.1
unnamed: C29.1, C30.2, R37.1
unnamed: C31.1, C32.2, R40.1
unnamed: C33.1, C34.2, R43.1
unnamed: C35.1, C36.2, R46.1
unnamed: C37.1, C38.2, R49.1
unnamed: C39.1, C40.2, R52.1
unnamed: C41.1, C42.2, R55.1
unnamed: C51.2, R57.1
unnamed: C52.2, R58.1
unnamed: C53.1, R58.2, R59.1, U13.1
unnamed: C54.2, R62.1
unnamed: C75.1, R65.1, R66.2, U13.7
unnamed: C76.2, R66.1
unnamed: C94.2, R70.1
unnamed: C107.2, R71.1
unnamed: D1.1 (K), L1.1, U4.2 (OUT)
unnamed: D2.2 (A), R77.1
unnamed: D3.1 (K), R90.1
unnamed: D4.2 (A), R91.1
unnamed: D5.2 (A), R92.2
unnamed: D6.1 (K), R93.2
unnamed: D7.2 (A), R94.2
unnamed: D8.2 (A), R95.1
unnamed: D9.2 (A), R96.1
unnamed: R4.1, R5.2, U1.1
unnamed: R7.1, RV1.1
unnamed: R8.1, RV1.4
unnamed: R6.2, R10.1, U1.7
unnamed: R4.2, U1.2 (-)
unnamed: R10.2, U1.6 (-)
unnamed: C109.1, R9.2, R11.1, U2.1 (ADJ)
unnamed: C110.1, R12.2, R13.2, U3.1 (ADJ)
unnamed: R1.1, U5.4 (AIN4)
unnamed: R2.1, U5.26 (AIN6)
unnamed: R3.1, U5.25 (AIN7)
unnamed: C15.1, R14.2, U6.3 (+)
unnamed: C18.1, R17.2, U6.5 (+)
unnamed: C20.1, R20.2, U7.3 (+)
unnamed: C22.1, R23.2, U7.5 (+)
unnamed: C24.1, R26.2, U8.3 (+)
unnamed: C26.1, R29.2, U8.5 (+)
unnamed: C28.1, R32.2, U9.3 (+)
unnamed: C30.1, R35.2, U9.5 (+)
unnamed: C32.1, R38.2, U10.3 (+)
unnamed: C34.1, R41.2, U10.5 (+)
unnamed: C36.1, R44.2, U11.3 (+)
unnamed: C38.1, R47.2, U11.5 (+)
unnamed: C40.1, R50.2, U12.3 (+)
unnamed: C42.1, R53.2, U12.5 (+)
unnamed: C51.1, R56.2, U13.3 (+)
unnamed: C53.2, R59.2, R60.1, U13.2 (-)
unnamed: C54.1, R64.2, U13.5 (+)
unnamed: C75.2, R63.1, R65.2, U13.6 (-)
unnamed: C85.1, R69.1, U14.8 (CKIN)
unnamed: R68.1, R74.1, U14.5 (IN)
unnamed: R70.2, U18.7 (INL)
unnamed: R71.2, U18.10 (INR)
unnamed: C91.1, U18.8 (VREF)
unnamed: R73.2, R95.2, U18.5 (~MUTE)
unnamed: R72.2, R96.2, U18.12 (~SHDN)

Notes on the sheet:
TFT_SCREEN
63Hz
7-Band Control
2.5KHz
Power
400Hz
160Hz
16KHz
LMC835N
Gyrators(63Hz - 16Khz)
6.3KHz
ATTENUATED AUDIO SIGNAL
Pre-Amp Stage
1KHz
LOGIC LEVEL SHIFTER 3.3V
MSGEQ7
SPEAKER AMP
TEENSY 4.1 (Microcontroller)

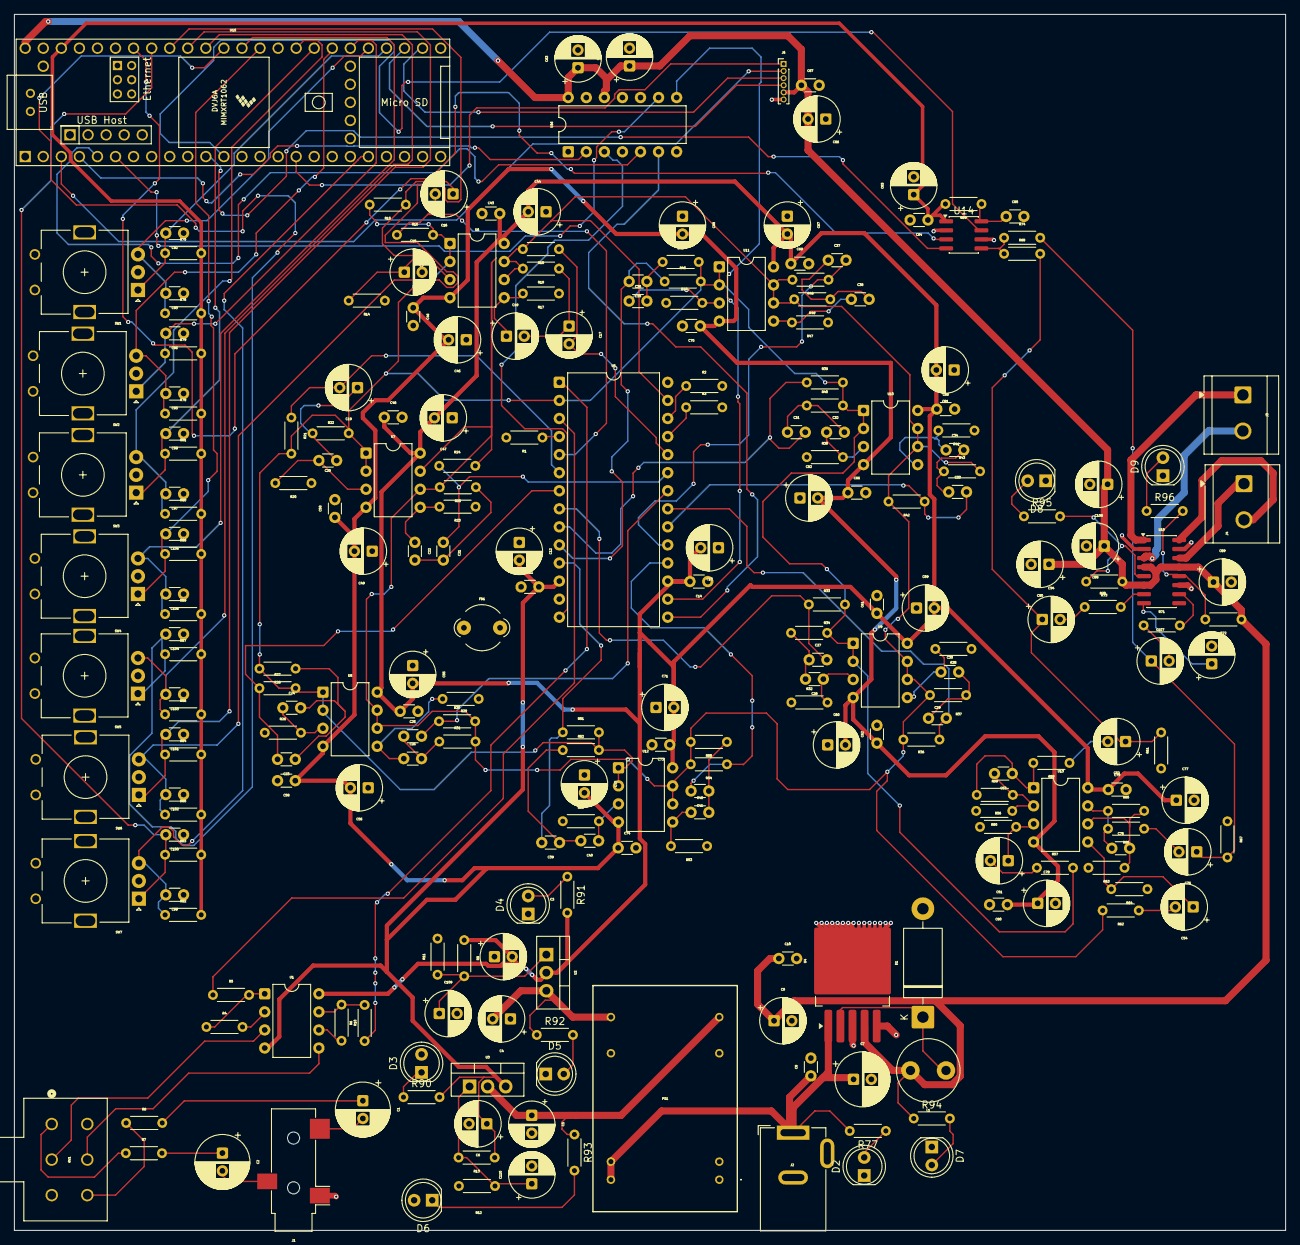
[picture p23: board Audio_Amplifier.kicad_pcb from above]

Board: 4 copper layers, 178.8 x 171.0 mm, 248 parts (0 on the bottom side), 133 nets.
